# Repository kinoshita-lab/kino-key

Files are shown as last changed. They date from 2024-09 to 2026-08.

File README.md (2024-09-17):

# Kino-Key25

[日本語](README.ja.md)

Open source piano-type keyboard MIDI controller project

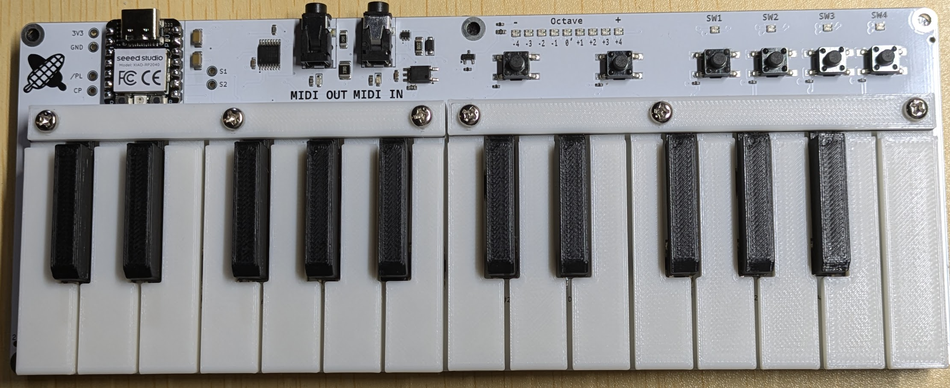
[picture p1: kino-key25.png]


## Features

- All mechanical parts are easy 3D-printable. You can also easly order to 3D printing manufactures, such as JLC3dP, etc. (we may sell mech parts in the future, but not planned)
- Software is implemented on small, cheap seeeduino xiao rp2040. Everything includes keyboard scanning is modifiable according to your preferences.
- Most of the components on the PCB is easy to buy(we may sell PCBA board for easier assembly in the future, but not planned)

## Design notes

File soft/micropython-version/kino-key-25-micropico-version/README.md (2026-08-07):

# Kino-Key25 — MicroPython port

MicroPython implementation of the Kino-Key25 USB-MIDI keyboard for the **Seeed XIAO RP2040**. A separate, parallel implementation of the C/C++ reference at [`../../kino-key-25-soft/`](../../kino-key-25-soft).

See [`AGENTS.md`](AGENTS.md) for the full project context and constraints.

## Hardware (GPIO)

| Signal | GPIO | Purpose |
|---|---|---|
| NPL | 6 | Shift-register latch/parallel-load (RP2040 out) |
| CLOCK  | 7 | Shift-register clock (RP2040 out) |
| OUT1 | 4 | Shift-register chain-1 serial data (RP2040 **in**) |
| OUT2 | 2 | Shift-register chain-2 serial data (RP2040 **in**) |
| NeoPixel data | 3 | WS2812 LED strip (14 LEDs) |

Source of truth for pin numbers: [`../../kino-key-25-soft/src/main.cpp`](../../kino-key-25-soft/src/main.cpp).

## Running application code (no build needed)

This project uses the **MicroPico** VSCode extension — **no PlatformIO**. Open this folder in VSCode, then:
- **Run** a file on-device (MicroPico: "Run"), or
- **Sync** files to the device (MicroPico: "Upload project").

> You need a custom MicroPython firmware on the XIAO RP2040 first. **USB-MIDI requires a custom firmware build (below).**

## Building the MicroPython firmware (needed for USB-MIDI)

Stock MicroPython exposes only USB-CDC (serial) — **not** the USB-MIDI class. To send MIDI over USB you must build a custom MicroPython rp2 firmware that adds a MIDI interface (USB descriptor + TinyUSB MIDI class driver). The standard build is below; the MIDI-specific source modifications are specified in the implementation notes (`.planning/02-micropython-usb-midi.md`).

### Prerequisites
- Python 3.8+, Git, CMake
- GNU Arm Embedded Toolchain (`arm-none-eabi-gcc`, 10.3+)
- A host C compiler (to build `mpy-cross`)

### Build steps (from a fresh clone)
```bash
mkdir firmware
cd firmware
git clone https://github.com/micropython/micropython
cd micropython
git checkout 06bcfd5b74c6d275ae0991a19dab8704299e4e05
git submodule update --init lib/pico-sdk lib/tinyusb

# 1) Build the MicroPython cross-compiler (host)
make -C mpy-cross

# 2) Fetch rp2 board submodules
cd ports/rp2
make submodules

# 3) Build the firmware for Seeed XIAO RP2040
make BOARD=SEEED_XIAO_RP2040
```

Output firmware:
```
ports/rp2/build-SEEED_XIAO_RP2040/firmware.uf2
```

### Flash to the board
1. Hold **BOOTSEL** on the XIAO RP2040 while plugging in USB (UF2 bootloader).
2. A mass-storage drive appears — copy `firmware.uf2` onto it.
3. The device reboots running the new firmware.

### Enabling USB-MIDI (the custom part)
Plain `make BOARD=SEEED_XIAO_RP2040` produces CDC-only firmware. To add the MIDI class and TinyUSB support, apply the provided patch file to your downloaded MicroPython repository before building:

```bash
cd /path/to/your/kino-key-25-micropico-version/firmware/micropython
patch -p1 < ../micropython_usb_midi.patch
```

Then compile and flash the firmware as usual. You will now be able to use `import usb_midi` in Python!

## Status
Basic functionality is implemented: key scanning (`shiftregister_scanner.py`), LED display (`led_display.py`), and USB-MIDI (`kino_midi.py`). Everything is tied together in `main.py`.

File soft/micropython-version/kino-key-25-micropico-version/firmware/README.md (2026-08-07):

# MicroPython Firmware Build Instructions

This directory contains the custom MicroPython firmware build required for USB-MIDI support on the Kino-Key25.

## Prerequisites
- Python 3.8+, Git, CMake
- GNU Arm Embedded Toolchain (`arm-none-eabi-gcc`, 10.3+)
- A host C compiler (to build `mpy-cross`)

## Build Steps

To ensure compatibility with the provided `micropython_usb_midi.patch`, we use a specific commit of MicroPython (`06bcfd5b74c6d275ae0991a19dab8704299e4e05`).

```bash
# 1. Clone MicroPython and checkout the verified commit
git clone https://github.com/micropython/micropython
cd micropython
git checkout 06bcfd5b74c6d275ae0991a19dab8704299e4e05
git submodule update --init lib/pico-sdk lib/tinyusb

# 2. Apply the USB-MIDI patch
# The patch adds the MIDI class descriptor and TinyUSB MIDI driver.
patch -p1 < ../micropython_usb_midi.patch

# 3. Build the MicroPython cross-compiler (host)
make -C mpy-cross

# 4. Fetch rp2 board submodules
cd ports/rp2
make submodules

# 5. Build the firmware for Seeed XIAO RP2040
make BOARD=SEEED_XIAO_RP2040
```

## Output Firmware
The compiled firmware will be located at:
```
micropython/ports/rp2/build-SEEED_XIAO_RP2040/firmware.uf2
```

## Flashing
1. Hold **BOOTSEL** on the XIAO RP2040 while plugging in USB (UF2 bootloader mode).
2. A mass-storage drive will appear. Copy `firmware.uf2` onto it.
3. The device will reboot running the new firmware with `usb_midi` support enabled.

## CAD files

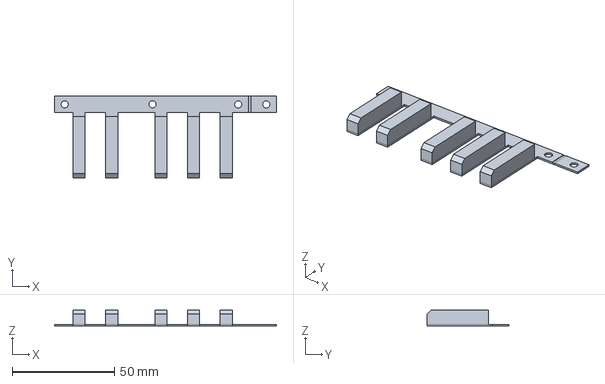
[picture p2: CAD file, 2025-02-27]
mech/black_C_C.FCStd
108.8 x 40.0 x 7.81 mm

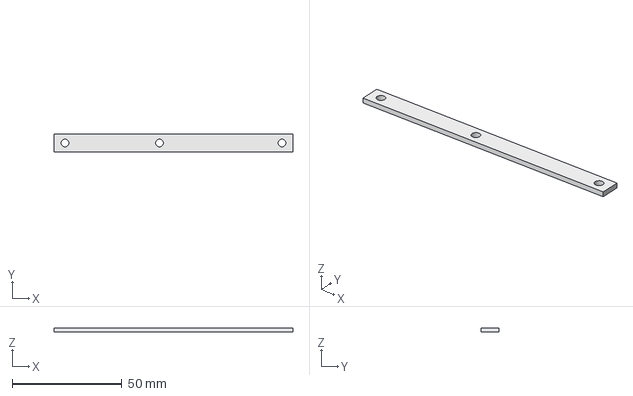
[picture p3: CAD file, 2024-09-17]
mech/key-bar_C_C_Top.FCStd
108.8 x 8.00 x 2.00 mm

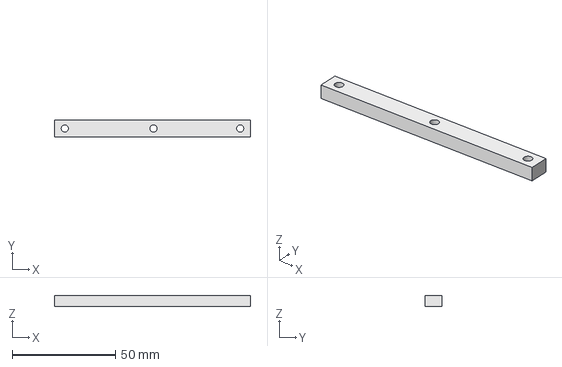
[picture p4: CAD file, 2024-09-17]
mech/key-bar_C_B_Bottom.FCStd
95.0 x 8.00 x 5.50 mm

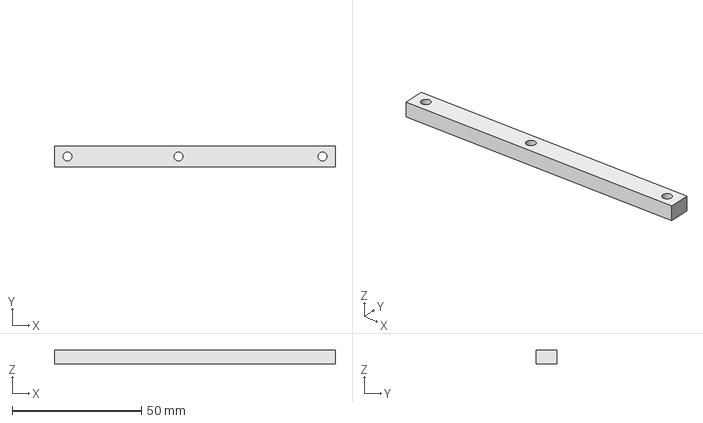
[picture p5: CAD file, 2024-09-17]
mech/key-bar_C_C_Bottom.FCStd
108.8 x 8.00 x 5.50 mm

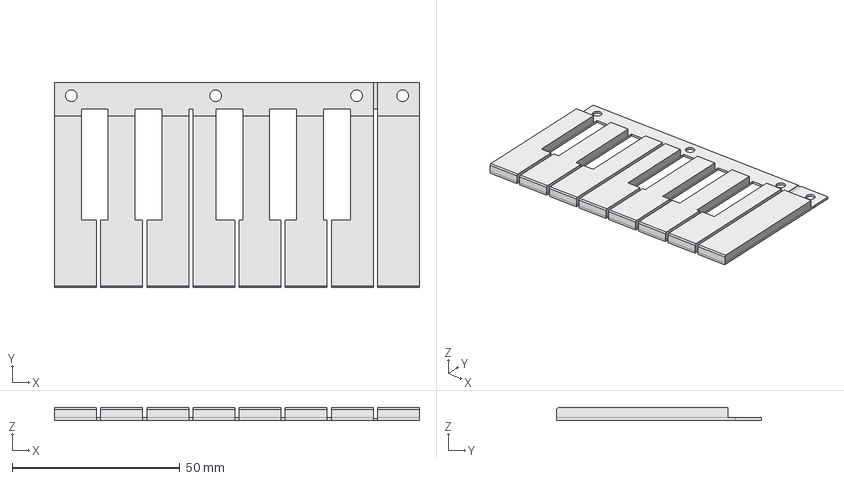
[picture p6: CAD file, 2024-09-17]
mech/white_C_C.FCStd
108.8 x 61.2 x 3.81 mm

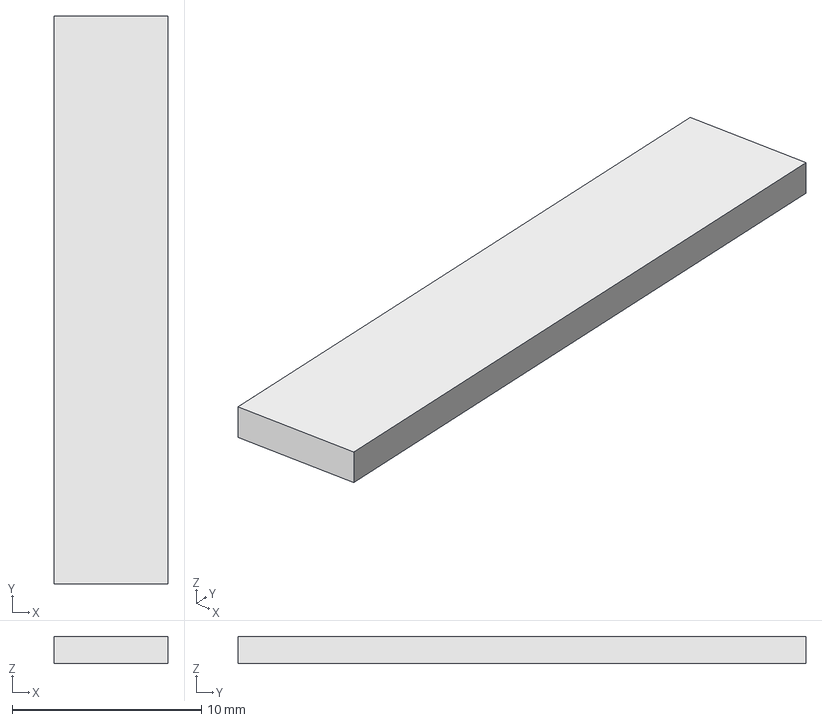
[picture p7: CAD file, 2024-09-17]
mech/black_key_bottom.FCStd
6.00 x 30.0 x 1.44 mm

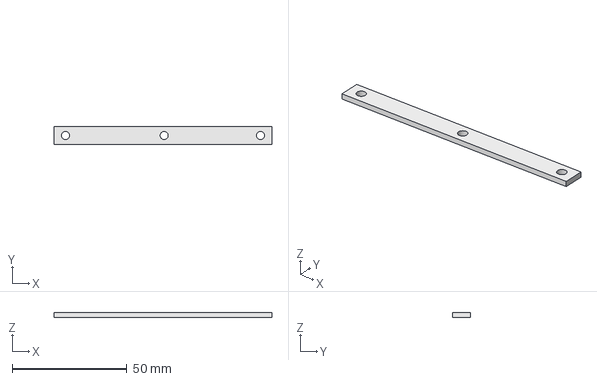
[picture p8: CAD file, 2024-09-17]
mech/key-bar_C_B_Top.FCStd
95.0 x 8.00 x 2.00 mm

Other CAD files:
mech/key-bar_C_B.FCStd
mech/key-bar_C_C.FCStd
mech/STL/black_C_C.stl
mech/STL/black_Key_bottom.stl
mech/STL/key-bar_C_B.stl
mech/STL/key-bar_C_B_Top.stl
mech/STL/key-bar_C_C.stl
mech/STL/key-bar_C_C_Top.stl
mech/STL/white_C_C.stl

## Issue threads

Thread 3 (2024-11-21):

Separate Mech Design for FDM and others e.g. SLA

kinoshita-lab, 2024-11-21:
Current design has additional "bottom plates" to make black keys' bottom level are aligned to white ones, because of  FDM printing has some restrictions not satisfying desired flatness when using supporting material and removing them after finishing.

This problem would not happen when printing by other methods such as SLA.

It would be a good solution to separate designs for SLA and others.

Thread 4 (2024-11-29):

Make PCB wider for upper/bottom case

kinoshita-lab, 2024-11-29:
too narrow to put anything currently, especially upper  materials.

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

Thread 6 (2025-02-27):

Remove voltage conversion for neopixels

kinoshita-lab, 2025-02-27:
Not working at all.
Works fine if remove conversion circuit without any problems.

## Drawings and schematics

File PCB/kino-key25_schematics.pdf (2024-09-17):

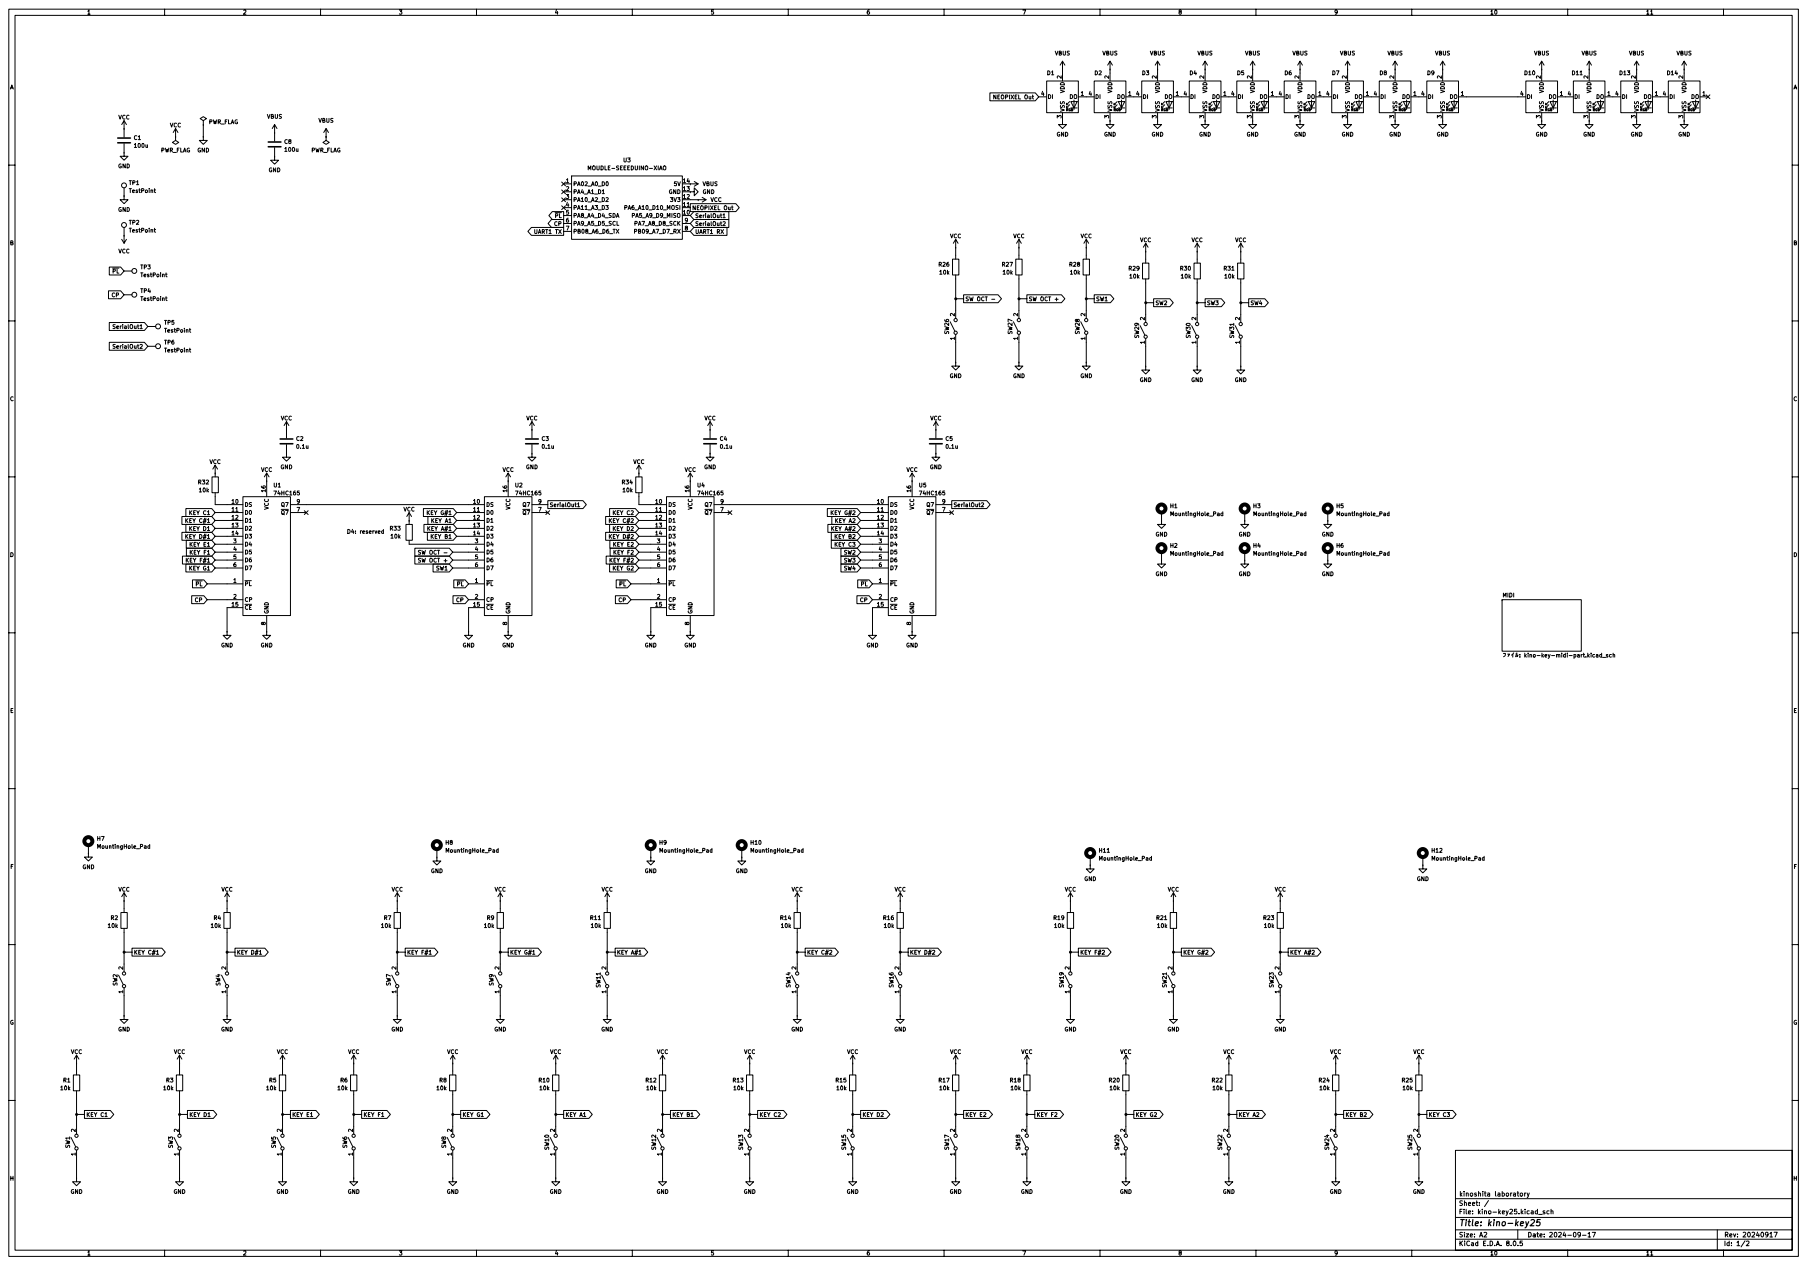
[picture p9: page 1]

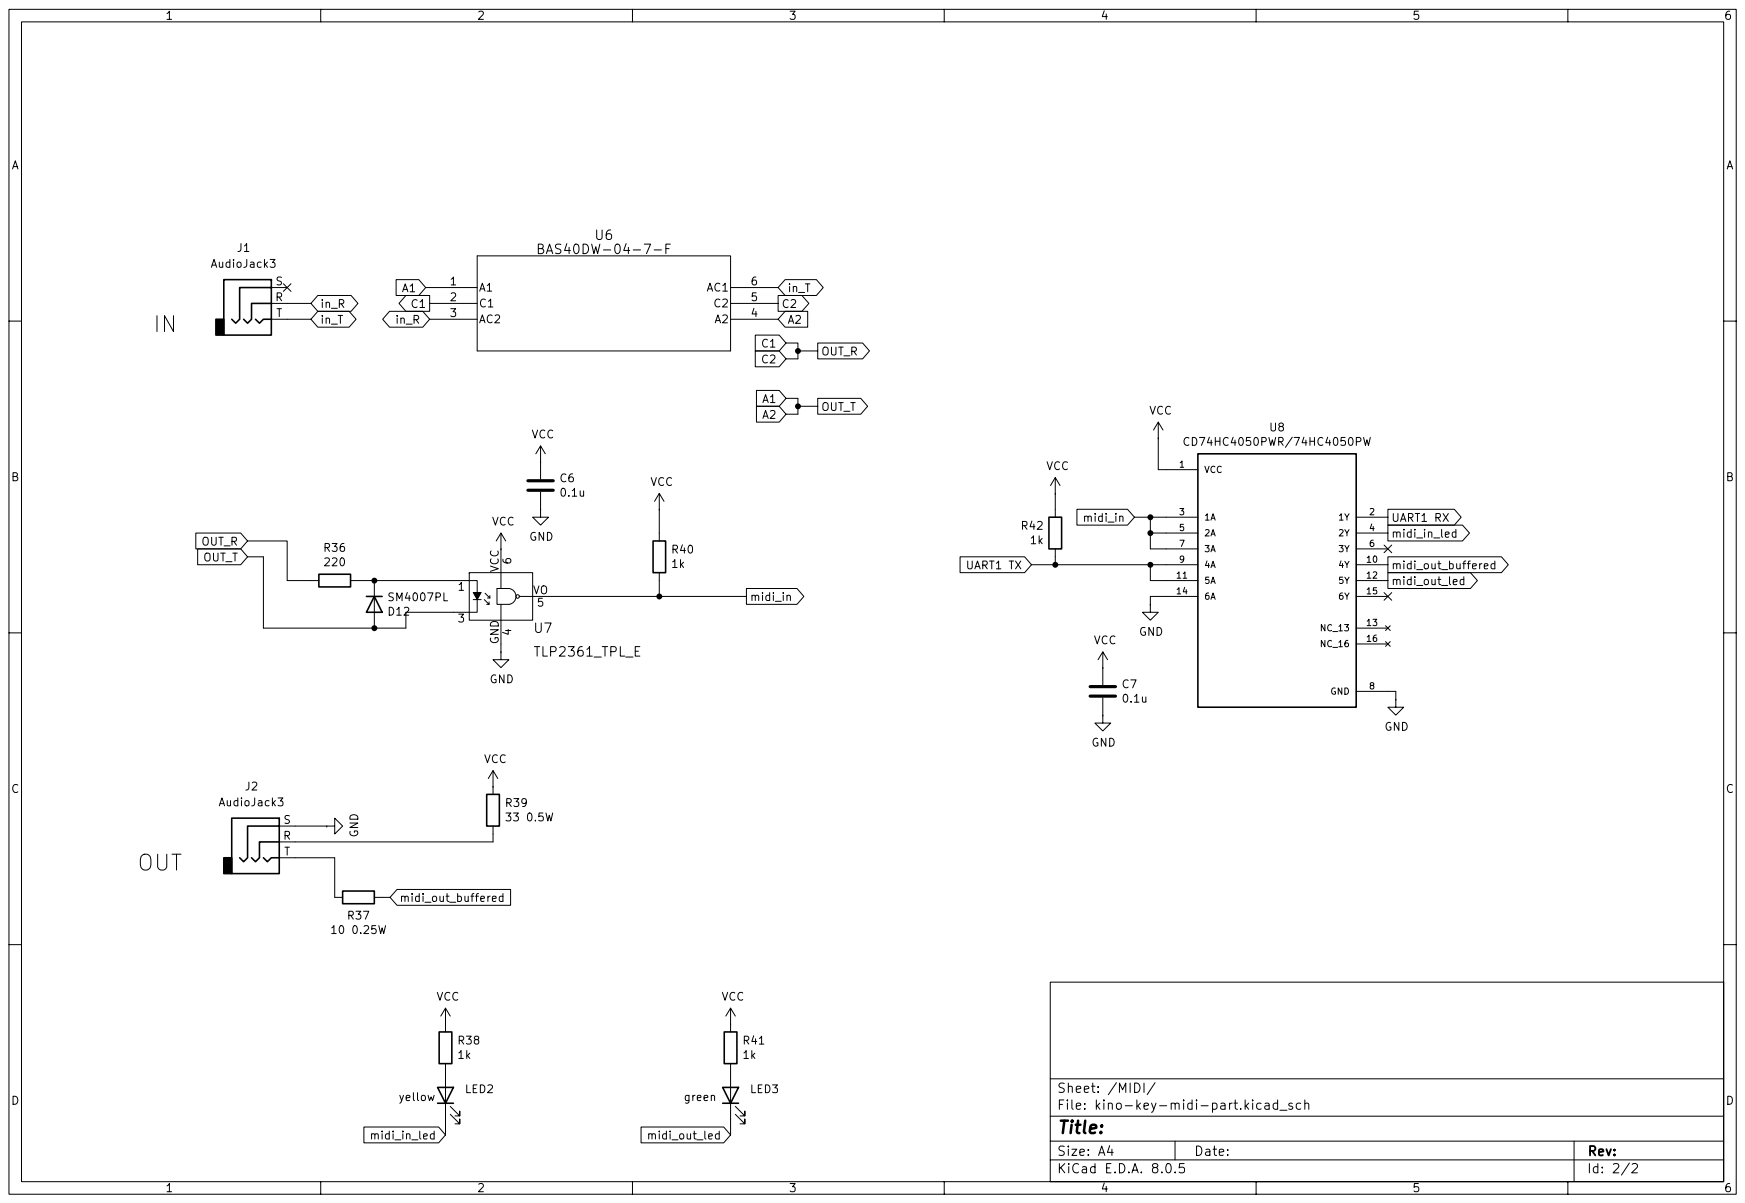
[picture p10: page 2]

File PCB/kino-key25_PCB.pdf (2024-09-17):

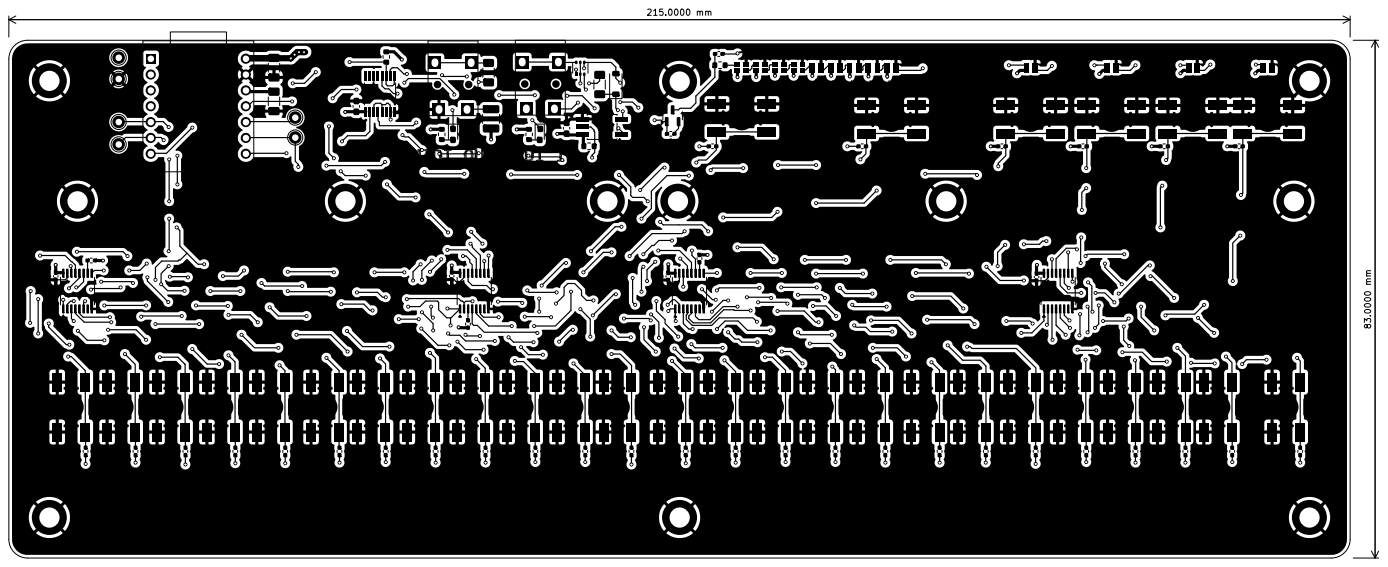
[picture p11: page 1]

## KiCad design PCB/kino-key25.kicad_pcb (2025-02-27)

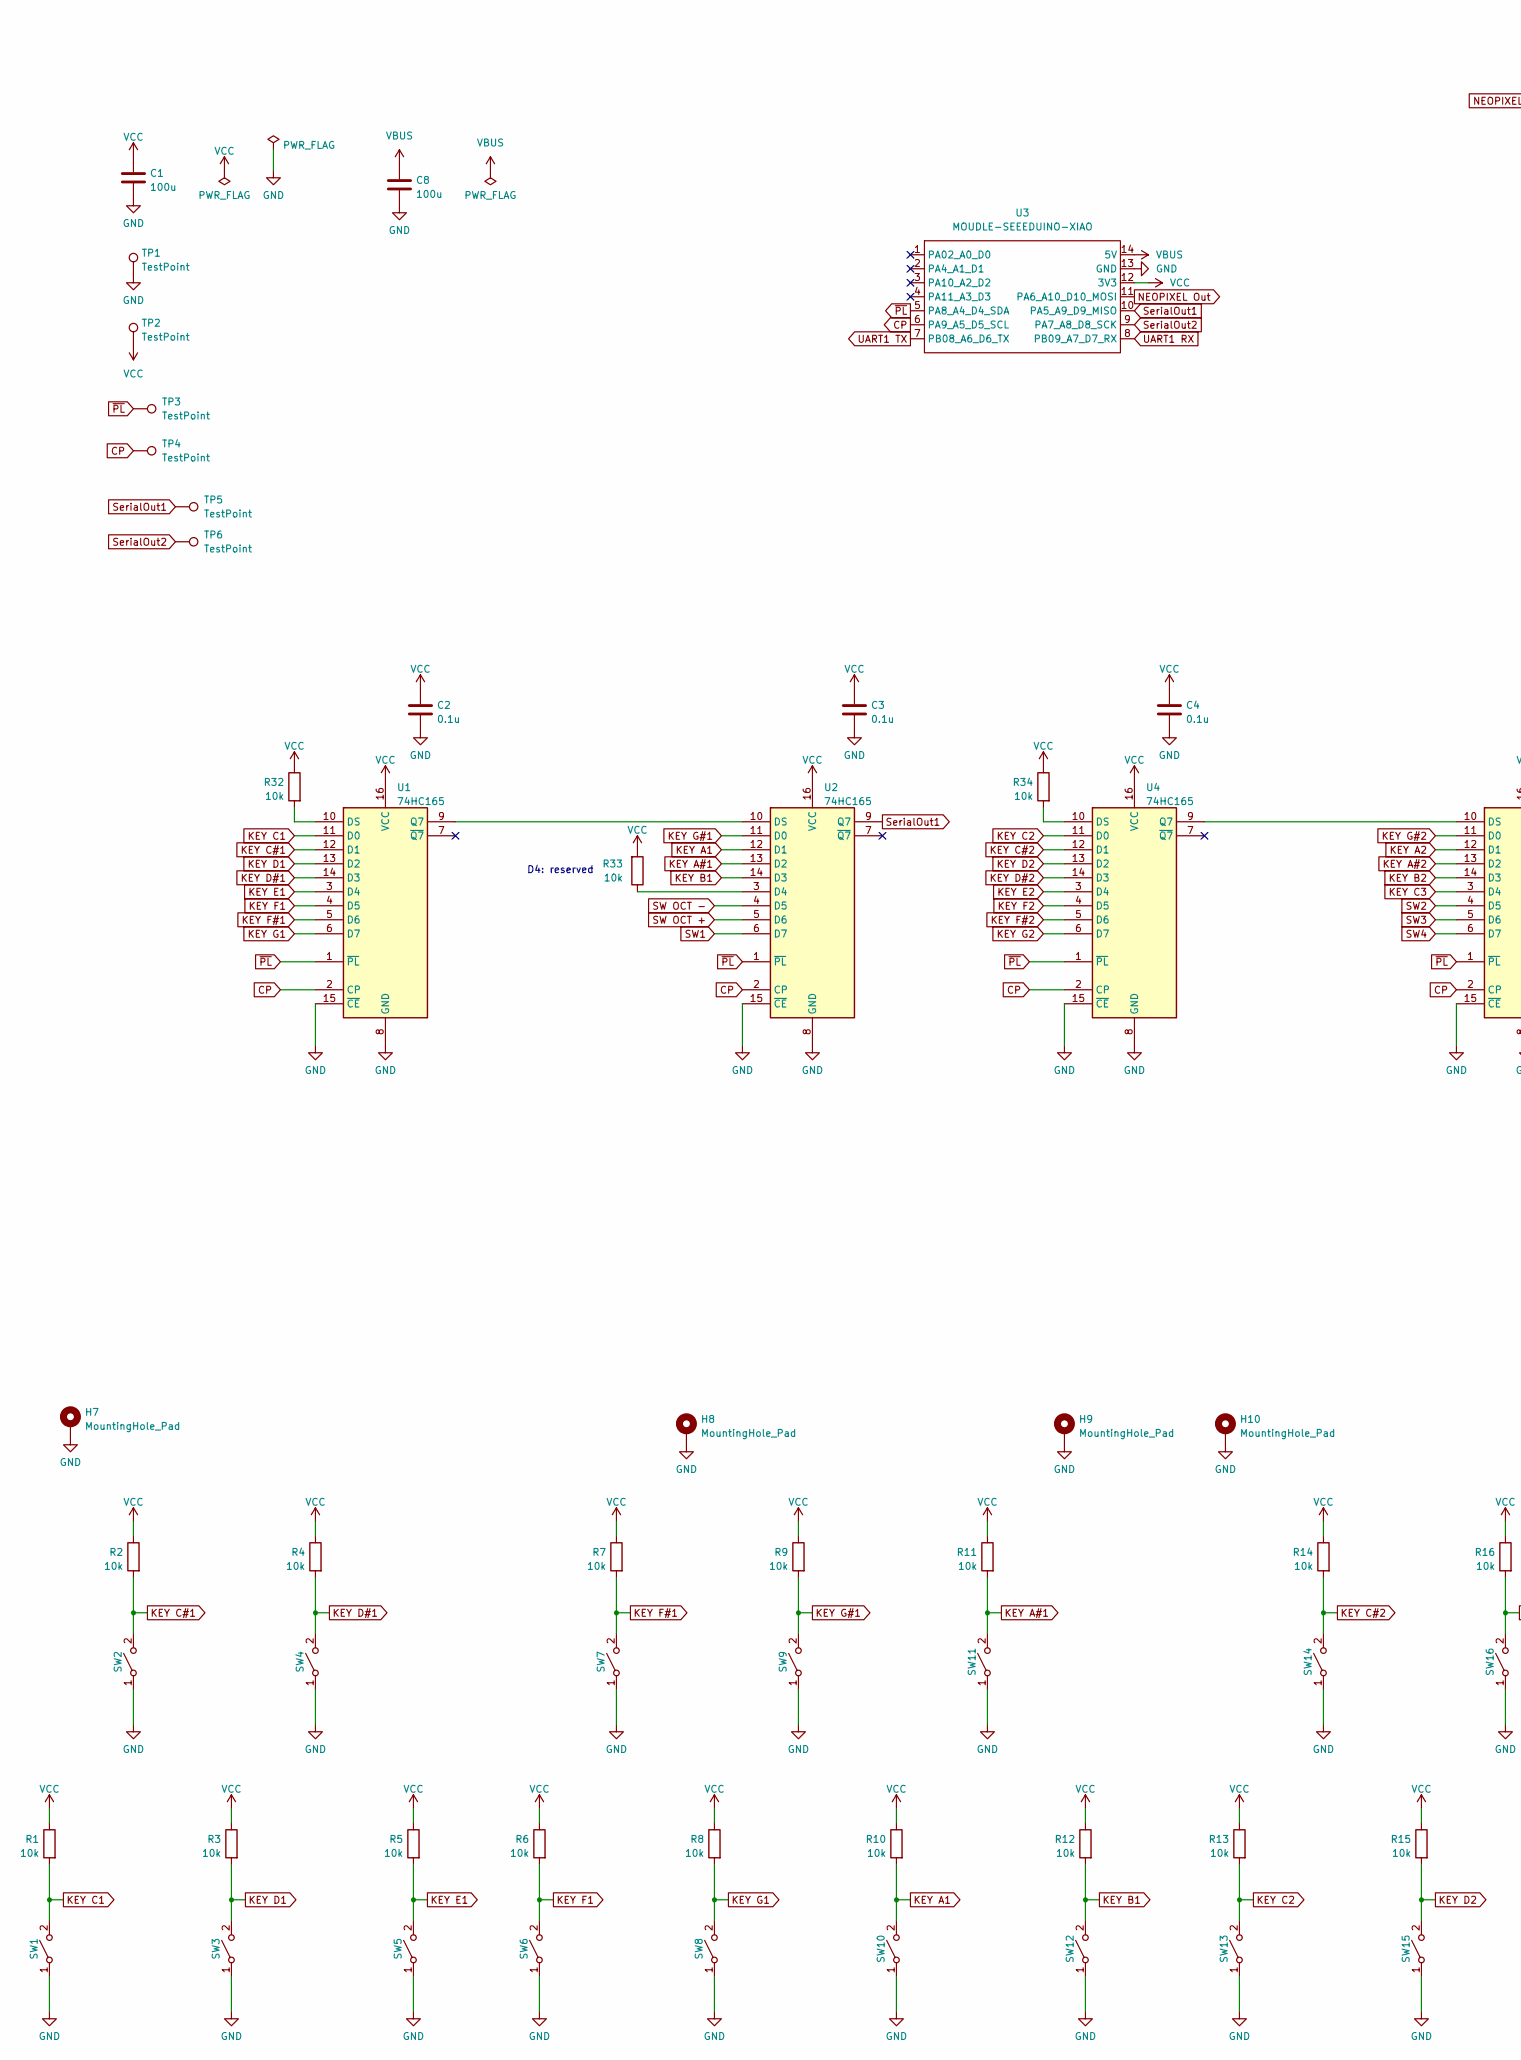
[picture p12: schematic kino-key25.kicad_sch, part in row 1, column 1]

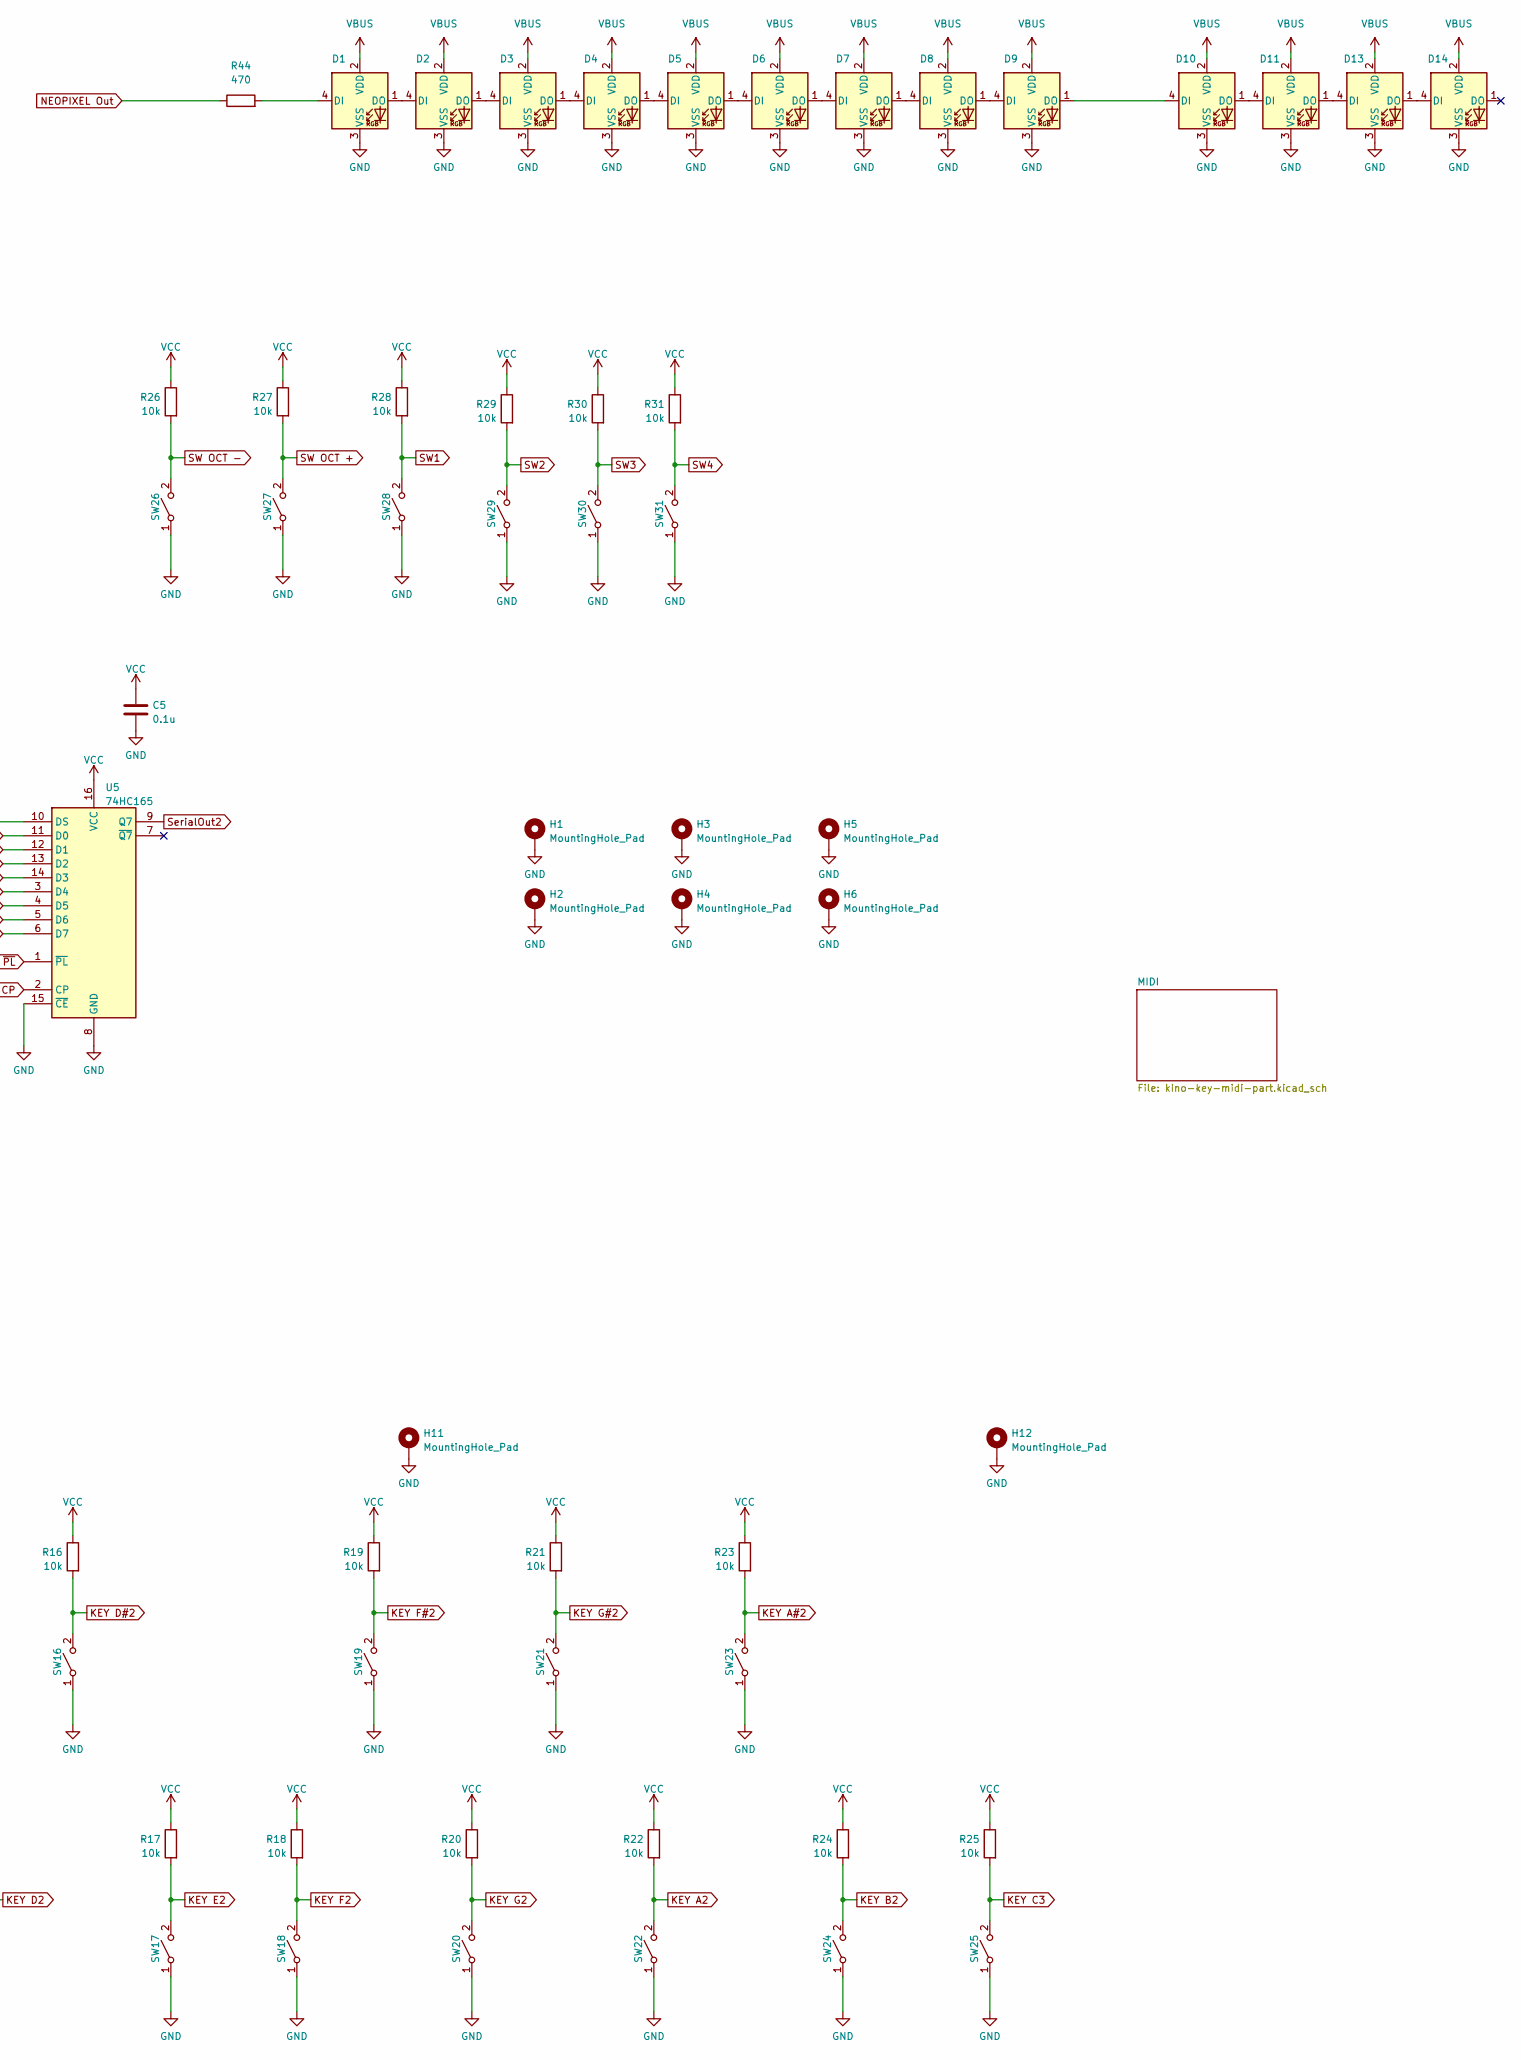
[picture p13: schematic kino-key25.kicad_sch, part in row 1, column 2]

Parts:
C1, C8: 100u; C_1206_3216Metric_Pad1.33x1.80mm_HandSolder; LCSC C312983
C2, C3, C4, C5: 0.1u; C_0402_1005Metric_Pad0.74x0.62mm_HandSolder; LCSC C1525
D1, D2, D3, D4, D5, D6, D7, D8, D9, D10, D11, D13, D14: LED_NeoPixel_XL-1615RGBC-WS2812B; LCSC C5349954
H1, H2, H3, H4, H5, H6, H7, H8, H9, H10, H11, H12: MountingHole_Pad; MountingHole_3.2mm_M3_DIN965_Pad
R1, R2, R3, R4, R5, R6, R7, R8, R9, R10, R11, R12, R13, R14, R15, R16, R17, R18, R19, R20, R21, R22, R23, R24, R25, R26, R27, R28, R29, R30, R31, R32, R33, R34: 10k; R_0402_1005Metric_Pad0.72x0.64mm_HandSolder; LCSC C25744
R44: 470; R_0603_1608Metric; LCSC C23179
SW1, SW2, SW3, SW4, SW5, SW6, SW7, SW8, SW9, SW10, SW11, SW12, SW13, SW14, SW15, SW16, SW17, SW18, SW19, SW20, SW21, SW22, SW23, SW24, SW25, SW26, SW27, SW28, SW29, SW30, SW31: SW_SPST; SW_Tactile_6mm_x_6mm_Futsuuno_SMD; LCSC C294566
TP1, TP2, TP3, TP4, TP5, TP6: TestPoint; TestPoint_THTPad_D2.0mm_Drill1.0mm
U1, U2, U4, U5: 74HC165; TSSOP-16_4.4x5mm_P0.65mm; LCSC C80696
U3: MOUDLE-SEEEDUINO-XIAO; Seeduino_Xiao_RP2040_MOUDLE14P-2.54-21X17.8MM

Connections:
CP: TP4.1, U1.2 (CP), U2.2 (CP), U3.6 (PA9_A5_D5_SCL), U4.2 (CP), U5.2 (CP)
GND: C1.2, C2.2, C3.2, C4.2, C5.2, C8.2, D1.3 (VSS), D2.3 (VSS), D3.3 (VSS), D4.3 (VSS), D5.3 (VSS), D6.3 (VSS), D7.3 (VSS), D8.3 (VSS), D9.3 (VSS), D10.3 (VSS), D11.3 (VSS), D13.3 (VSS), D14.3 (VSS), H1.1, H2.1, H3.1, H4.1, H5.1, H6.1, H7.1, H8.1, H9.1, H10.1, H11.1, H12.1, SW1.1 (A), SW2.1 (A), SW3.1 (A), SW4.1 (A), SW5.1 (A), SW6.1 (A), SW7.1 (A), SW8.1 (A), SW9.1 (A), SW10.1 (A), SW11.1 (A), SW12.1 (A), SW13.1 (A), SW14.1 (A), SW15.1 (A), SW16.1 (A), SW17.1 (A), SW18.1 (A), SW19.1 (A), SW20.1 (A), SW21.1 (A), SW22.1 (A), SW23.1 (A), SW24.1 (A), SW25.1 (A), SW26.1 (A), SW27.1 (A), SW28.1 (A), SW29.1 (A), SW30.1 (A), SW31.1 (A), TP1.1, U1.8 (GND), U1.15 (~CE), U2.8 (GND), U2.15 (~CE), U3.13 (GND), U4.8 (GND), U4.15 (~CE), U5.8 (GND), U5.15 (~CE); also elsewhere on the board
KEY A1: R10.2, SW10.2 (B), U2.12 (D1)
KEY A2: R22.2, SW22.2 (B), U5.12 (D1)
KEY A#1: R11.2, SW11.2 (B), U2.13 (D2)
KEY A#2: R23.2, SW23.2 (B), U5.13 (D2)
KEY B1: R12.2, SW12.2 (B), U2.14 (D3)
KEY B2: R24.2, SW24.2 (B), U5.14 (D3)
KEY C1: R1.2, SW1.2 (B), U1.11 (D0)
KEY C2: R13.2, SW13.2 (B), U4.11 (D0)
KEY C3: R25.2, SW25.2 (B), U5.3 (D4)
KEY C#1: R2.2, SW2.2 (B), U1.12 (D1)
KEY C#2: R14.2, SW14.2 (B), U4.12 (D1)
KEY D1: R3.2, SW3.2 (B), U1.13 (D2)
KEY D2: R15.2, SW15.2 (B), U4.13 (D2)
KEY D#1: R4.2, SW4.2 (B), U1.14 (D3)
KEY D#2: R16.2, SW16.2 (B), U4.14 (D3)
KEY E1: R5.2, SW5.2 (B), U1.3 (D4)
KEY E2: R17.2, SW17.2 (B), U4.3 (D4)
KEY F1: R6.2, SW6.2 (B), U1.4 (D5)
KEY F2: R18.2, SW18.2 (B), U4.4 (D5)
KEY F#1: R7.2, SW7.2 (B), U1.5 (D6)
KEY F#2: R19.2, SW19.2 (B), U4.5 (D6)
KEY G1: R8.2, SW8.2 (B), U1.6 (D7)
KEY G2: R20.2, SW20.2 (B), U4.6 (D7)
KEY G#1: R9.2, SW9.2 (B), U2.11 (D0)
KEY G#2: R21.2, SW21.2 (B), U5.11 (D0)
NEOPIXEL Out: R44.1, U3.11 (PA6_A10_D10_MOSI)
unnamed: D1.4 (DI), R44.2
unnamed: D1.1 (DO), D2.4 (DI)
unnamed: D2.1 (DO), D3.4 (DI)
unnamed: D3.1 (DO), D4.4 (DI)
unnamed: D4.1 (DO), D5.4 (DI)
unnamed: D5.1 (DO), D6.4 (DI)
unnamed: D6.1 (DO), D7.4 (DI)
unnamed: D7.1 (DO), D8.4 (DI)
unnamed: D8.1 (DO), D9.4 (DI)
unnamed: D9.1 (DO), D10.4 (DI)
unnamed: D10.1 (DO), D11.4 (DI)
unnamed: D11.1 (DO), D13.4 (DI)
unnamed: D13.1 (DO), D14.4 (DI)
unnamed: R32.2, U1.10 (DS)
unnamed: U1.9 (Q7), U2.10 (DS)
unnamed: R33.1, U2.3 (D4)
unnamed: R34.2, U4.10 (DS)
unnamed: U4.9 (Q7), U5.10 (DS)
SW1: R28.2, SW28.2 (B), U2.6 (D7)
SW2: R29.2, SW29.2 (B), U5.4 (D5)
SW3: R30.2, SW30.2 (B), U5.5 (D6)
SW4: R31.2, SW31.2 (B), U5.6 (D7)
SW OCT +: R27.2, SW27.2 (B), U2.5 (D6)
SW OCT -: R26.2, SW26.2 (B), U2.4 (D5)
SerialOut1: TP5.1, U2.9 (Q7), U3.10 (PA5_A9_D9_MISO)
SerialOut2: TP6.1, U3.9 (PA7_A8_D8_SCK), U5.9 (Q7)
UART1 RX: U3.8 (PB09_A7_D7_RX); also elsewhere on the board
UART1 TX: U3.7 (PB08_A6_D6_TX); also elsewhere on the board
VBUS: C8.1, D1.2 (VDD), D2.2 (VDD), D3.2 (VDD), D4.2 (VDD), D5.2 (VDD), D6.2 (VDD), D7.2 (VDD), D8.2 (VDD), D9.2 (VDD), D10.2 (VDD), D11.2 (VDD), D13.2 (VDD), D14.2 (VDD), U3.14 (5V)
VCC: C1.1, C2.1, C3.1, C4.1, C5.1, R1.1, R2.1, R3.1, R4.1, R5.1, R6.1, R7.1, R8.1, R9.1, R10.1, R11.1, R12.1, R13.1, R14.1, R15.1, R16.1, R17.1, R18.1, R19.1, R20.1, R21.1, R22.1, R23.1, R24.1, R25.1, R26.1, R27.1, R28.1, R29.1, R30.1, R31.1, R32.1, R33.2, R34.1, TP2.1, U1.16 (VCC), U2.16 (VCC), U3.12 (3V3), U4.16 (VCC), U5.16 (VCC); also elsewhere on the board
~PL: TP3.1, U1.1 (~PL), U2.1 (~PL), U3.5 (PA8_A4_D4_SDA), U4.1 (~PL), U5.1 (~PL)

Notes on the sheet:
D4: reserved

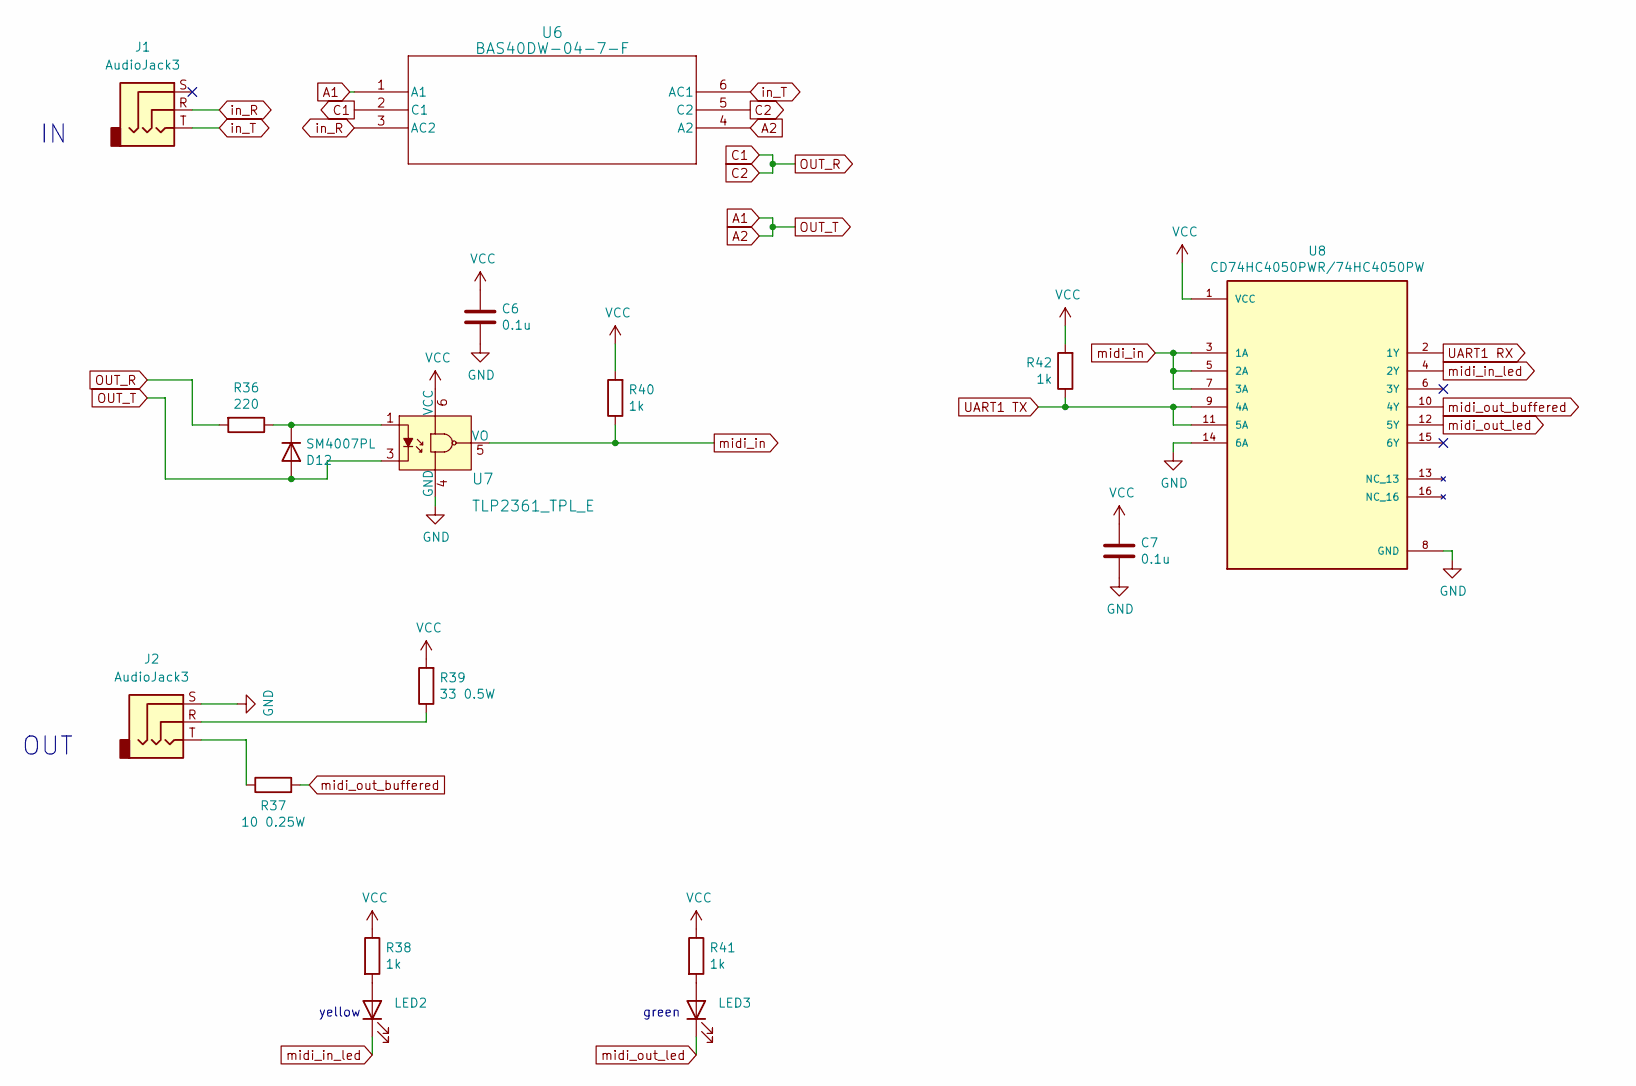
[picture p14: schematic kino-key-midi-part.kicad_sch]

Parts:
C6, C7: 0.1u; C_0603_1608Metric_Pad1.08x0.95mm_HandSolder; LCSC C14663
D12: SM4007PL; D_SOD-123; LCSC C64898
J1, J2: AudioJack3; 3.5mm_Stereo_TRS_PJ-3210-4A_and_ST-005-G
LED2: 19-213/Y2C-CQ2R2L/3T(CY); LED_0603_1608Metric_Pad1.05x0.95mm_HandSolder; LCSC C72038
LED3: 19-217/GHC-YR1S2/3T; LED_0603_1608Metric_Pad1.05x0.95mm_HandSolder; LCSC C2994781
R36: 220; R_1206_3216Metric_Pad1.30x1.75mm_HandSolder; LCSC C17957
R37: 10 0.25W; R_1206_3216Metric_Pad1.30x1.75mm_HandSolder; LCSC C17903
R38, R40, R41, R42: 1k; R_0603_1608Metric; LCSC C21190
R39: 33 0.5W; R_1210_3225Metric_Pad1.30x2.65mm_HandSolder; LCSC C407192
U6: BAS40DW-04-7-F; SOT-363_DIO; LCSC C134364
U7: TLP2361_TPL_E; SO-5_4.4x3.6mm_P1.27mm; MPN TLP2361(TPL,E; Digi-Key_PN TLP2361(TPLECT-ND
U8: CD74HC4050PWR/74HC4050PW; SOP65P640X120-16N; PARTREV February 2005; LCSC C546991

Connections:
A1: D12.2 (A), U6.1 (A1), U6.4 (A2), U7.3
C1: R36.2, U6.2 (C1), U6.5 (C2)
GND: C6.2, C7.2, J2.S, U7.4 (GND), U8.8 (GND), U8.14 (6A); also elsewhere on the board
unnamed: D12.1 (K), R36.1, U7.1
unnamed: J2.R, R39.1
unnamed: J2.T, R37.1
unnamed: LED2.2 (A), R38.2
unnamed: LED3.2 (A), R41.2
UART1 RX: U8.2 (1Y); also elsewhere on the board
UART1 TX: R42.1, U8.9 (4A), U8.11 (5A); also elsewhere on the board
VCC: C6.1, C7.1, R38.1, R39.2, R40.2, R41.1, R42.2, U7.6 (VCC), U8.1 (VCC); also elsewhere on the board
in_R: J1.R, U6.3 (AC2)
in_T: J1.T, U6.6 (AC1)
midi_in: R40.1, U7.5 (VO), U8.3 (1A), U8.5 (2A), U8.7 (3A)
midi_in_led: LED2.1 (K), U8.4 (2Y)
midi_out_buffered: R37.2, U8.10 (4Y)
midi_out_led: LED3.1 (K), U8.12 (5Y)

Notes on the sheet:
green
OUT
yellow

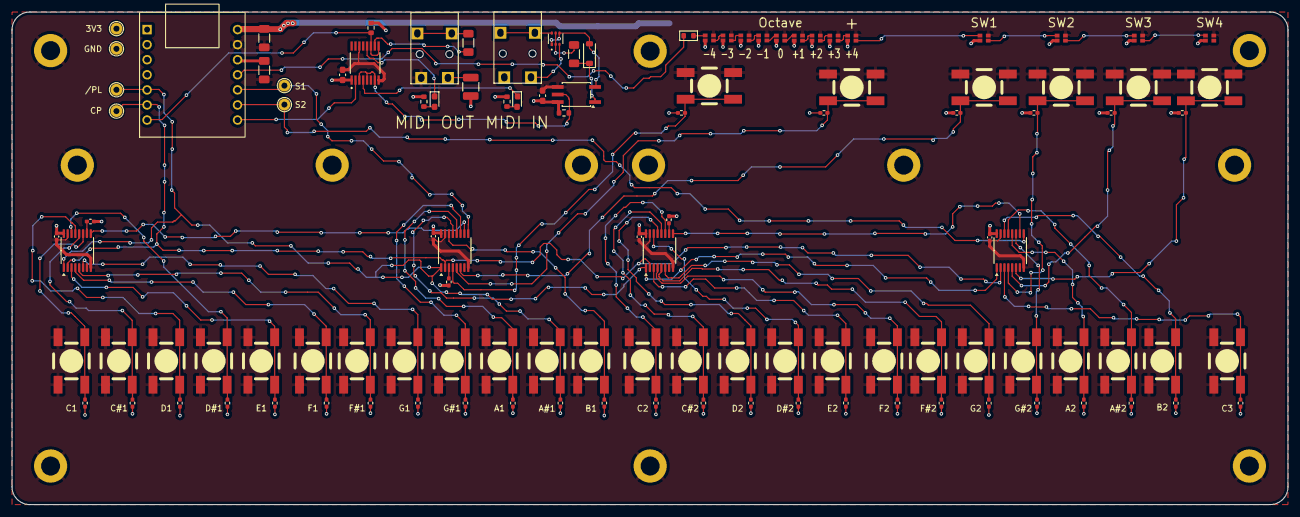
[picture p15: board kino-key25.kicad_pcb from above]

Board: 2 copper layers, 215.0 x 83.0 mm, 125 parts (0 on the bottom side), 72 nets.

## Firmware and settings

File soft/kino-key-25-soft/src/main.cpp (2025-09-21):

#include "MIDI.h"
#include "ShiftregisterSwScanner.hpp"
#include <Adafruit_TinyUSB.h>
#include <Arduino.h>
#include "LedDisplay.hpp"

enum
{
    kNUM_KEYS = 25,
};

enum
{
    kNPL_PIN   = 6,
    kCLOCK_PIN = 7,

    kOUTPUT_PIN_1 = 4,
    kOUTPUT_PIN_2 = 2,

    kNeoPixelData_PIN = 3,
};

enum
{
    kSwitchIndexOctMinus = 13,
    kSwitchIndexOctPlus  = 14,
    kSwitchIndexSw1      = 15,

    kSwitchIndexSw2 = kinoshita_lab::ShiftregisterSwScanner25Keys::DEFAULT_NUM_SWITCH_EACH + 13,
    kSwitchIndexSw3 = kinoshita_lab::ShiftregisterSwScanner25Keys::DEFAULT_NUM_SWITCH_EACH + 14,
    kSwitchIndexSw4 = kinoshita_lab::ShiftregisterSwScanner25Keys::DEFAULT_NUM_SWITCH_EACH + 15,
};
struct KeyScanStatus
{
    bool shouldSend;
    bool offOn;
    KeyScanStatus() : shouldSend(false), offOn(false) {}
};
KeyScanStatus keyScanStatus[kNUM_KEYS];

struct NoteKeyInfo
{
    bool offOn     = false;
    int byKeyIndex = -1;
};
NoteKeyInfo noteKeyInfo[128];

struct ControllerStatus
{
    int midi_channel       = 1;
    int octave             = 0;
    bool shouldSendNoteOff = false;
    int program            = 0;
    bool sendProgramChange = false;
    enum
    {
        kOctaveMin = 0,
        kOctaveMax = 9,
    };
};
ControllerStatus controllerStatus;

Adafruit_USBD_MIDI usb_midi;
MIDI_CREATE_INSTANCE(Adafruit_USBD_MIDI, usb_midi, MIDI_USB);
MIDI_CREATE_INSTANCE(HardwareSerial, Serial1, serial_midi);

kinoshita_lab::kinokey_25::LedDisplay<kNeoPixelData_PIN> led_display;

void switchHandler(uint32_t switch_index, const int off_on);

kinoshita_lab::ShiftregisterSwScanner25Keys scanner(kNPL_PIN, kCLOCK_PIN,
                                                    kOUTPUT_PIN_1,
                                                    kOUTPUT_PIN_2,
                                                    switchHandler, 16, 1);

inline int clip(const int min, const int max, const int value)
{
    return value < min ? min : (value > max ? max : value);
}

void switchHandler(uint32_t switch_index, const int off_on)
{
    if (switch_index < 16) {
        // keys
        if (kSwitchIndexOctMinus > switch_index) {
            keyScanStatus[switch_index].shouldSend = true;
            keyScanStatus[switch_index].offOn      = off_on;
        }

        // otherwise
        if (switch_index == kSwitchIndexOctMinus) {
            if (off_on) {
                controllerStatus.octave = clip(ControllerStatus::kOctaveMin, ControllerStatus::kOctaveMax,
                                               controllerStatus.octave - 1);
                led_display.setOctave(controllerStatus.octave);
                Serial.printf("octave: %d\n", controllerStatus.octave);
            }
        }
        if (switch_index == kSwitchIndexOctPlus) {
            if (off_on) {
                controllerStatus.octave = clip(ControllerStatus::kOctaveMin, ControllerStatus::kOctaveMax,
                                               controllerStatus.octave + 1);

                led_display.setOctave(controllerStatus.octave);
            }
        }
        if (switch_index == kSwitchIndexSw1) { // program change -
            if (off_on) {
                controllerStatus.program           = clip(0, 127, controllerStatus.program - 1);
                controllerStatus.sendProgramChange = true;
            }
            led_display.setSw1(off_on);
        }

    } else {
        // keys
        if (switch_index < kSwitchIndexSw2) {
            const auto offset                               = 4;
            keyScanStatus[switch_index - offset].shouldSend = true;
            keyScanStatus[switch_index - offset].offOn      = off_on;
            Serial.printf("key index:%d\n", switch_index - offset);
        }

        // otherwise
        if (switch_index == kSwitchIndexSw2) { // program change +
            if (off_on) {
                controllerStatus.program           = clip(0, 127, controllerStatus.program + 1);
                controllerStatus.sendProgramChange = true;
            }
            led_display.setSw2(off_on);
        }

        if (switch_index == kSwitchIndexSw3) { // ch 1
            if (off_on) {
                controllerStatus.midi_channel      = 1;
                controllerStatus.shouldSendNoteOff = true;
                led_display.setSw3(off_on);
            }
        }

        if (switch_index == kSwitchIndexSw4) {
            if (off_on) {
                controllerStatus.midi_channel      = 10; // ch 2 drum
                controllerStatus.shouldSendNoteOff = true;
                led_display.setSw4(off_on);
            }
        }
    }
}

void sendNoteOn(const int note, const int velocity)
{
    if (note > INT8_MAX) {
        return;
    }
    const auto channel = controllerStatus.midi_channel;

    MIDI_USB.sendNoteOn(note, velocity, channel);
    serial_midi.sendNoteOn(note, velocity, channel);
    Serial.printf("note on %d\n", note);
}

void sendNoteOff(const int note, const int velocity)
{
    if (note > INT8_MAX) {
        return;
    }
    const auto channel = controllerStatus.midi_channel;
    MIDI_USB.sendNoteOff(note, velocity, channel);
    serial_midi.sendNoteOff(note, velocity, channel);
    Serial.printf("note off %d\n", note);
}

void sendProgramChange(const int program)
{
    const auto channel = controllerStatus.midi_channel;
    MIDI_USB.sendProgramChange(program, channel);
    serial_midi.sendProgramChange(program, channel);
}

void setup()
{
    for (int i = 0; i < kNUM_KEYS; i++) {
        keyScanStatus[i].shouldSend = false;
        keyScanStatus[i].offOn      = false;
    }

    // put your setup code here, to run once:
    MIDI_USB.begin(MIDI_CHANNEL_OMNI);
    serial_midi.begin(MIDI_CHANNEL_OMNI);
    Serial.begin(115200);
    delay(100);
    controllerStatus.octave = 5;
    led_display.setOctave(controllerStatus.octave);
    led_display.setSw3(true);
}

void setup1()
{
    led_display.initialize();
}

void loop1()
{
    led_display.loop();
}

void loop()
{

    scanner.update();

    if (controllerStatus.shouldSendNoteOff) {
        Serial.println("send note off");
        for (int i = 0; i < INT8_MAX; i++) {
            if (noteKeyInfo[i].offOn) {
                noteKeyInfo[i].offOn = false;
                sendNoteOff(i, 0);
            }
        }
        controllerStatus.shouldSendNoteOff = false;
    }

    if (controllerStatus.sendProgramChange) {
        controllerStatus.sendProgramChange = false;
        sendProgramChange(controllerStatus.program);
    }

    for (int i = 0; i < kNUM_KEYS; i++) {
        if (keyScanStatus[i].shouldSend) {
            keyScanStatus[i].shouldSend = false;
            const auto numNotePerOctave = 12;
            auto note                   = numNotePerOctave * controllerStatus.octave + i;
            if (keyScanStatus[i].offOn) {
                if (note >= INT8_MAX) {
                    break;
                }
                sendNoteOn(note, 127);
                noteKeyInfo[note].offOn      = true;
                noteKeyInfo[note].byKeyIndex = i;
            } else {
                const auto offset = note % numNotePerOctave;
                for (auto oct = 0; oct < ControllerStatus::kOctaveMax + 2; oct++) {
                    const auto actual_note = numNotePerOctave * oct + offset;
                    if (actual_note >= INT8_MAX) {
                        break;
                    }
                    if (noteKeyInfo[actual_note].byKeyIndex == i) {
                        if (noteKeyInfo[actual_note].offOn) {
                            noteKeyInfo[actual_note].offOn      = false;
                            noteKeyInfo[actual_note].byKeyIndex = -1;
                            sendNoteOff(actual_note, 0);
                            break;
                        }
                    }
                }
            }
        }
    }
}

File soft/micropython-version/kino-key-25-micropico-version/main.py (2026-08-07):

import utime
from shiftregister_scanner import ShiftregisterSwScanner
from led_display import LedDisplay
import kino_midi

# Pin definitions
NPL_PIN = 6
CLOCK_PIN = 7
OUTPUT_PIN_1 = 4
OUTPUT_PIN_2 = 2
NEOPIXEL_PIN = 3

NUM_KEYS = 25

kSwitchIndexOctMinus = 13
kSwitchIndexOctPlus  = 14
kSwitchIndexSw1      = 15

kSwitchIndexSw2 = 16 + 13
kSwitchIndexSw3 = 16 + 14
kSwitchIndexSw4 = 16 + 15

class ControllerStatus:
    def __init__(self):
        self.midi_channel = 0  # 0-indexed (Ch 1)
        self.octave = 5
        self.program = 0
        self.kOctaveMin = 0
        self.kOctaveMax = 9

controller = ControllerStatus()
led = LedDisplay(NEOPIXEL_PIN)

# Keep track of active notes to turn them off correctly if octave changes
note_key_info = {i: -1 for i in range(128)}  # note -> switch_index (-1 means off)

def clip(min_val, max_val, val):
    return max(min_val, min(max_val, val))

def switch_handler(switch_index, off_on):
    global controller
    
    if switch_index < 16:
        # keys
        if switch_index < kSwitchIndexOctMinus:
            handle_key(switch_index, off_on)
        
        # function switches
        elif switch_index == kSwitchIndexOctMinus and off_on:
            controller.octave = clip(controller.kOctaveMin, controller.kOctaveMax, controller.octave - 1)
            led.set_octave(controller.octave)
            
        elif switch_index == kSwitchIndexOctPlus and off_on:
            controller.octave = clip(controller.kOctaveMin, controller.kOctaveMax, controller.octave + 1)
            led.set_octave(controller.octave)
            
        elif switch_index == kSwitchIndexSw1:
            if off_on:
                controller.program = clip(0, 127, controller.program - 1)
                kino_midi.program_change(controller.program, controller.midi_channel)
            led.set_sw1(off_on)

    else:
        # keys
        if switch_index < kSwitchIndexSw2:
            offset = 4
            handle_key(switch_index - offset, off_on)
            
        # function switches
        elif switch_index == kSwitchIndexSw2:
            if off_on:
                controller.program = clip(0, 127, controller.program + 1)
                kino_midi.program_change(controller.program, controller.midi_channel)
            led.set_sw2(off_on)
            
        elif switch_index == kSwitchIndexSw3:
            if off_on:
                turn_off_all_notes()
                controller.midi_channel = 0 # Ch 1
                led.set_sw3(True)
                
        elif switch_index == kSwitchIndexSw4:
            if off_on:
                turn_off_all_notes()
                controller.midi_channel = 9 # Ch 10 (drums)
                led.set_sw4(True)

def handle_key(key_index, off_on):
    num_note_per_octave = 12
    note = num_note_per_octave * controller.octave + key_index
    
    if off_on:
        if note < 128:
            kino_midi.note_on(note, 127, controller.midi_channel)
            note_key_info[note] = key_index
    else:
        offset = key_index % num_note_per_octave
        for oct_val in range(controller.kOctaveMax + 2):
            actual_note = num_note_per_octave * oct_val + offset
            if actual_note < 128 and note_key_info[actual_note] == key_index:
                note_key_info[actual_note] = -1
                kino_midi.note_off(actual_note, 0, controller.midi_channel)
                break

def turn_off_all_notes():
    for note in range(128):
        if note_key_info[note] != -1:
            note_key_info[note] = -1
            kino_midi.note_off(note, 0, controller.midi_channel)

def setup():
    kino_midi.init_serial_midi()  # Initialize UART MIDI OUT
    led.set_octave(controller.octave)
    led.set_sw3(True)

def main():
    scanner = ShiftregisterSwScanner(NPL_PIN, CLOCK_PIN, OUTPUT_PIN_1, OUTPUT_PIN_2, switch_handler)
    setup()
    
    print("Kino-Key25 MicroPython MIDI Keyboard Started.")
    while True:
        try:
            scanner.update()
            led.loop()
            utime.sleep_ms(4)
        except KeyboardInterrupt:
            turn_off_all_notes()
            led.clear()
            led.loop()
            break

if __name__ == '__main__':
    main()

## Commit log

2024-09-01 [mech] Add FreeCAD and exported stl files
    [black_C_C.FCStd, black_C_C.stl, key-bar_C_B.FCStd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]
2024-09-17 add mech design
    [black_C_C.FCStd, black_C_C.stl, black_Key_bottom.stl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]
2024-09-17 Add rest of files
    [kino-key-midi-part.kicad_sch, kino-key25.kicad_pcb, kino-key25.kicad_sch]
2024-09-17 add pdf schematics
    [kino-key25.kicad_sch]
2025-02-27 [mech] Open and save with FreeCad 1.0
    [black_C_C.FCStd]
2025-02-27 [PCB] Update to KiCad 9.0, remove voltage conversion #6
    [kino-key-midi-part.kicad_sch, kino-key25.kicad_pcb, kino-key25.kicad_sch]
2026-08-07 Add initial MicroPython application files (key scan, LED display, USB-MIDI)
